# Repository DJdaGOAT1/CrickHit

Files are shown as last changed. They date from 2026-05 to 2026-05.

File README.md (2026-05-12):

# CrickHit
### An Embedded Real-Time Cricket Game on the TI MSPM0G3507

---

## Project Overview

CrickHit is a real-time cricket batting game built from scratch on the **TI MSPM0G3507 LaunchPad** with a **ST7735R 128x160 TFT LCD**. The player controls a batsman using a slide potentiometer and physical switches to hit balls bowled with realistic curve trajectories. The game runs entirely on bare-metal interrupts with no RTOS, using fixed-point physics, sprite compositing, a custom 5-bit binary-weighted DAC for audio, and multilingual UI support.

Developed as the final project for **ECE 319H: Introduction to Embedded Systems (Honors)** at **The University of Texas at Austin**, Spring 2026.

**Authors:** Devansh Joshi and Calum Cheah

---

## Gameplay / Demo

A top-down cricket scene is rendered on the LCD. A bowler at the top of the screen delivers balls toward the stumps at the bottom. The player moves the batsman horizontally with a slide potentiometer and triggers left or right bat swings using physical switches.

A demo of CrickHit is available [here](https://youtu.be/25Vt4UJRmN4):

Video Thumbnail Title (https://www.youtube.com/watch?v=25Vt4UJRmN4)

### Scoring

Runs are awarded based on how precisely the bat contacts the ball:

| Result | Condition | Runs |
|---|---|---|
| Perfect Hit | Ball within 3px of ideal contact point | +6 |
| Good Hit | Ball within 8px of ideal contact point | +4 |
| Hit | Ball within 14px of ideal contact point | +2 |
| Wide | Ball delivered too far from the batsman | +1 |
| Wicket (OUT) | Ball hits the stumps without being hit | Score resets |

Swinging on the correct side (left swing for balls approaching from the left, right swing for the right) gives a threshold bonus. Swinging on the wrong side applies a 2px penalty to all scoring thresholds, making it harder to score high.

### Ball Physics

Each delivery uses kinematic equations with 6-bit fixed-point arithmetic for sub-pixel precision:
- Initial horizontal velocity is randomized
- A curve acceleration (`ax`) is computed so the ball arcs toward the stumps
- Target position uses a Gaussian random distribution (Central Limit Theorem approximation) so slower deliveries aim more accurately at the stumps while faster ones scatter wider
- Speed-proportional jitter is added to the scoring calculation to prevent quantization lockout at high speeds, where the large step size would otherwise restrict the ball to only a few Y positions in the hit zone

### Wide Detection

A ball is called wide if it passes the batsman's reach without being hit:
- **Off-wide:** Ball passes more than 15px past the batsman's right edge
- **Leg-wide:** Ball is left of the pitch with a gap greater than 3px from the batsman's left edge

If a wide ball subsequently hits the stumps or gets hit by the bat, the wide run is revoked.

### Game Controls

| Input | Action |
|---|---|
| Slide potentiometer | Move batsman left/right |
| LEFT switch (PA25) | Swing bat to the left |
| RIGHT switch (PA27) | Swing bat to the right |
| TOP switch (PA24) | Increase ball delivery speed |
| BOTTOM switch (PA26) | Decrease ball delivery speed |
| TOP + BOTTOM | Return to home screen |
| LEFT + RIGHT | Pause / unpause |
| S1 (LaunchPad) | Enable speaker |
| S2 (LaunchPad) | Disable speaker |

A 1500ms cooldown is enforced between swings to prevent spam.

---

## Hardware

### Platform
- **MCU:** TI MSPM0G3507 LaunchPad (ARM Cortex-M0+, 80 MHz)
- **Display:** ST7735R 128x160 TFT LCD over SPI

### Pin Assignments

| Peripheral | Pin(s) | Function |
|---|---|---|
| SPI1 SCLK | PB9 | LCD clock |
| SPI1 CS | PB6 | LCD chip select |
| SPI1 MOSI | PB8 | LCD data |
| LCD Reset | PB15 | ST7735 !RST |
| LCD D/C | PA13 | ST7735 RS (Data/Command) |
| Slide Pot | PB18 (ADC1 Ch5) | Batsman horizontal position |
| 5-bit DAC | PB0-PB4 | Binary-weighted audio output |
| Speaker Enable | PB12 | Active-low speaker control |
| TOP Switch | PA24 | Increase ball speed |
| LEFT Switch | PA25 | Left bat swing |
| BOTTOM Switch | PA26 | Decrease ball speed |
| RIGHT Switch | PA27 | Right bat swing |
| LED 0 | PA15 | 2-run hit indicator |
| LED 1 | PA16 | 4-run hit indicator |
| LED 2 | PA17 | 6-run hit indicator |

### Required Components
- MSPM0G3507 LaunchPad
- ST7735R 128x160 TFT LCD
- Slide potentiometer
- 4 momentary push switches
- 5-bit binary-weighted DAC
- Speaker with enable circuit
- 3 LEDs with current-limiting resistors

### Custom PCB

We designed a custom PCB in KiCad that consolidates all of the hardware circuitry onto a single board. The PCB integrates the ST7735R LCD connector, the 5-bit binary-weighted DAC, the speaker amplifier circuit (MCP34119P), all four game switches, the slide potentiometer input, LED indicators, IR receiver (TSOP31438), a ULN2003B Darlington driver, UART debugging header, and TExaS connector -- all routed to the MSPM0G3507 LaunchPad. This eliminates the need for breadboard wiring and makes the entire system compact and reliable.

### 3D-Printed Enclosure

A custom controller-style enclosure was designed in **Autodesk Fusion** to house the PCB and LaunchPad together as a handheld game controller.




An STL of the enclosure is included in the `3D_Enclosure/`

---

## Software Architecture

### Interrupt-Driven Design

The entire game runs on three interrupt sources with no polling loops in the main thread:

| ISR | Source | Rate | Purpose |
|---|---|---|---|
| `TIMG12_IRQHandler` | TimerG12 | 30 Hz | Main game tick: polls ADC, updates all sprite positions, runs collision detection, sets render flag |
| `TIMG0_IRQHandler` | TimerG0 | 1 kHz | Swing cooldown timer (counts up to 1500ms between allowed swings) |
| SysTick | SysTick | 11 kHz | Streams audio samples through the 5-bit DAC |

The main loop blocks on a flag set by the 30 Hz ISR, then handles rendering, UI updates, and screen transitions. All ST7735 drawing occurs in main context only, never inside an ISR.

### Object-Oriented Sprite System

A `Sprite` base class provides position tracking, dirty-flag rendering, overlap detection, and background-aware erasure. Four derived classes implement the game objects:

**Ball** -- Fixed-point position (`fx`, `fy`) and velocity (`vx`, `vy`) with curve acceleration (`ax`). A 5-state machine drives the lifecycle:
```
IDLE --> BOWLING --> HIT_LEFT/HIT_RIGHT --> RESET --> IDLE
                 \-> (stump collision) --> RESET --> IDLE
```

**Batsman** -- Position mapped from the slide potentiometer ADC reading (calibrated range 1587-192). Left swing has 8 animation frames, right swing has 10. The current frame pointer is updated each game tick during a swing.

**Bowler** -- Cycles through 7 animation frames. Frame 4 is the release frame, which triggers ball delivery with randomized trajectory parameters.

**Stump** -- Two frames (intact and broken). On wicket, the broken frame displays for 30 game ticks (~1 second) before the OUT screen appears.

### Rendering Pipeline

The `Renderer` module composites sprites against the pitch background to prevent texture artifacts:

1. For each pixel in a sprite, check if it's transparent (`BG_COLOR = 0x9772`)
2. If transparent, fetch the corresponding pixel from the pitch bitmap (or outfield green if outside the pitch bounds)
3. White crease pixels in the pitch are substituted with pitch surface color to avoid visual bleed
4. The composed buffer is written as a single SPI transaction for flicker-free output

`EraseToBackground()` restores the pitch texture when a sprite moves, handling the partial-width erase case when the batsman slides left or right.

### Audio System

Three sound effects are stored as raw sample arrays and played through a 5-bit binary-weighted DAC at 11 kHz via SysTick:

| Sound | Samples | Trigger |
|---|---|---|
| IPL Stadium | 28,179 | Title screen crowd atmosphere |
| Bat Hit | 2,239 | Ball contacts bat |
| Stump Hit | 3,592 | Ball hits stumps (wicket) |

The speaker can be muted/unmuted at runtime via the LaunchPad S1/S2 buttons, controlled through GPIO PB12.

### Internationalization

The game supports **English** and **Spanish**, selectable on the home screen:
- TOP switch selects English, BOTTOM switch selects Spanish
- All UI strings ("Score"/"Puntaje", "Wide"/"Ancha", instruction text) are stored in a `Phrases[][]` lookup table
- A Devanagari (Hindi) font renderer (`HindiFont.h/cpp`) with 31 glyphs and diacritic support is included for future localization

---

## Project Structure

```
CrickHit/
|-- README.md
|-- LICENSE
|-- mspm0g3507.cmd                 Linker script
|
|-- src/                           Game source code
|   |-- Lab9HMain.cpp              Main game loop, ISRs, collision detection, game state
|   |-- GameDefs.h                 All constants: sprite dimensions, physics params, thresholds
|   |-- Sprites.h                  Sprite class hierarchy (Sprite, Ball, Batsman, Bowler, Stump)
|   |-- Sprite.cpp                 Base class: draw, erase, overlap detection
|   |-- Ball.cpp                   Fixed-point kinematics, trajectory, state machine
|   |-- Batsman.cpp                Potentiometer input mapping, swing animation
|   |-- Bowler.cpp                 Bowling animation, release frame detection
|   |-- Stump.cpp                  Intact/broken state, hit animation
|   |-- Renderer.h / .cpp          Background-compositing sprite renderer
|   |-- Screens.h / .cpp           Home, instruction, pause, and OUT screens + i18n
|   |-- Sound.h / .cpp             DAC audio playback (SysTick-driven)
|   |-- LED.h / .cpp               Hit-quality LED indicators
|   |-- Switch.h / .cpp            4-switch input reading
|   |-- SmallFont.h / .cpp         Numeric score display font
|   +-- HindiFont.h / .cpp         Devanagari script renderer (31 glyphs, 12x16px)
|
|-- inc/                           Hardware abstraction libraries (see Acknowledgments)
|   |-- Clock.h / .cpp             System clock configuration (80 MHz PLL)
|   |-- DAC5.h / .cpp              5-bit DAC GPIO driver
|   |-- LaunchPad.h / .cpp         LaunchPad GPIO and button initialization
|   |-- SPI.h / .cpp               SPI communication driver
|   |-- ST7735.h / .cpp            ST7735 LCD driver (drawing, text, bitmaps)
|   |-- SlidePot.h / .cpp          Slide potentiometer ADC driver
|   |-- TExaS.h / .cpp             TExaS grading and logic analyzer system
|   |-- Timer.h / .cpp             Hardware timer configuration and arming
|   |-- SysTick.s                  SysTick assembly routines
|   +-- msp.s                      MSP device assembly support
|
|-- images/                        Sprite assets
|   |-- images.h                   All sprite bitmap data as C arrays (RGB565, 16-bit)
|   |-- ball/                      Ball sprite source BMP
|   |-- batsman/                   Batsman idle + 7 swing frame BMPs
|   |-- bowler/                    7 bowling animation frame BMPs
|   |-- stump/                     Intact and broken stump BMPs
|   |-- pitch/                     35x140 pitch surface bitmap
|   +-- BmpConvert16.exe           BMP-to-RGB565 C array converter
|
|-- sounds/                        Audio assets
|   |-- sounds.h                   Audio sample arrays
|   |-- ipl_stadium.wav            Title screen crowd audio
|   |-- bat_hit.wav                Bat contact sound effect
|   +-- stump.wav                  Wicket sound effect
|
|-- PCB_Design/                    KiCad project for the custom game PCB
|   |-- CrickHit_PCB.kicad_sch    Schematic
|   |-- CrickHit_PCB.kicad_pcb    PCB layout
|   |-- CrickHit_PCB.kicad_pro    Project file
|   |-- utece.kicad_sym            Custom symbol library
|   +-- logo.bmp                   Board silkscreen logo
|
|-- 3D_Enclosure/                  STL file for the controller enclosure
|   +-- Enclosure.stl
|
|-- tools/                         Development utilities
|   |-- curve.py                   Ball trajectory simulation for tuning physics
|   +-- flood_fill_sprites.py      Sprite transparency preprocessing
|
|-- ticlang/
|   +-- startup_mspm0g3507_ticlang.c   MCU startup and vector table
|
+-- targetConfigs/
    +-- MSPM0G3507.ccxml           Debug target configuration
```

---

## Building and Flashing

### Prerequisites
- **Code Composer Studio (CCS)** with the TI CLANG compiler (v4.0+)
- **MSPM0 SDK** (v2.9+)
- MSPM0G3507 LaunchPad with hardware wired per the pin assignments above

### Setup
1. Clone this repository into your CCS workspace
2. **File > Import > CCS Projects**, point to the cloned folder
3. Ensure the MSPM0 SDK is installed and `COM_TI_MSPM0_SDK_INSTALL_DIR` is set
4. Build the project -- the `inc/` folder contains all necessary driver libraries, so no external ValvanoWare dependency is needed
5. Connect the LaunchPad via USB and flash

The `inc/` directory contains the hardware abstraction libraries that originally lived in a shared `MSPM0_ValvanoWare/inc/` directory. Include paths have been updated so this project builds standalone.

---

## Development Utilities

**`curve.py`** -- Python script that simulates ball trajectories with the same kinematic equations used in the game. Plots predicted paths for tuning physics constants (velocity, acceleration, target variance) without reflashing the board.

**`flood_fill_sprites.py`** -- Post-processes `images.h` after BMP-to-C conversion. Flood-fills exterior background pixels with the transparent color (`0x9772`) while preserving interior white pixels (bat highlights, ball shine, etc.) that should not be treated as transparent during compositing.

---

## Acknowledgments

This project was built for **ECE 319H: Introduction to Embedded Systems (Honors)** at **The University of Texas at Austin**, taught by **Professor Ramesh Yerraballi**. Thank you to Dr. Yerraballi, Dr. Valvano, Dr. Chin, Dr. Holt, and the ECE319 TAs for their instruction and support throughout ECE319H!

The hardware abstraction libraries in the `inc/` directory -- Clock, DAC5, LaunchPad, SPI, ST7735, SlidePot, TExaS, and Timer -- were written by **Jonathan Valvano** as part of the [MSPM0 ValvanoWare](http://users.ece.utexas.edu/~valvano/) curriculum framework. These drivers provide the foundational embedded systems infrastructure (clock configuration, SPI communication, LCD rendering, ADC interfacing, timer management) that CrickHit is built on.

---

## Authors

**Devansh Joshi** -- [GitHub](https://github.com/devanshjoshi08)  
**Calum Cheah** -- [GitHub](https://github.com/CalumCheah)

---

## License

This project is licensed under the [MIT License](LICENSE).

The hardware abstraction libraries in `inc/` are provided by Jonathan Valvano and Texas Instruments under their own respective terms and are not covered by the MIT License.

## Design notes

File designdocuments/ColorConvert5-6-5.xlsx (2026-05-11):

red | green | blue | 565
0 | 255 | 120 | 0x7FE0 | 0x7FE0, // 0, 255, 120

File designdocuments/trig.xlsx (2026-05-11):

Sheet: 64
 | 2 |  | 64
angle | vx | vy | ix | iy
0 | 2 | 0 | 128 | 0
0.09817477042 | 1.990369453 | 0.1960342807 | 127 | 13
0.1963495408 | 1.961570561 | 0.390180644 | 126 | 25
0.2945243113 | 1.913880671 | 0.5805693545 | 122 | 37
0.3926990817 | 1.847759065 | 0.7653668647 | 118 | 49
0.4908738521 | 1.763842529 | 0.9427934737 | 113 | 60
0.5890486225 | 1.662939225 | 1.111140466 | 106 | 71
0.687223393 | 1.546020907 | 1.268786568 | 99 | 81
0.7853981634 | 1.414213562 | 1.414213562 | 91 | 91
0.8835729338 | 1.268786568 | 1.546020907 | 81 | 99
0.9817477042 | 1.111140466 | 1.662939225 | 71 | 106
1.079922475 | 0.9427934737 | 1.763842529 | 60 | 113
1.178097245 | 0.7653668647 | 1.847759065 | 49 | 118
1.276272016 | 0.5805693545 | 1.913880671 | 37 | 122
1.374446786 | 0.390180644 | 1.961570561 | 25 | 126
1.472621556 | 0.1960342807 | 1.990369453 | 13 | 127
1.570796327 | -7.656635742e-16 | 2 | 0 | 128
1.668971097 | -0.1960342807 | 1.990369453 | -13 | 127
1.767145868 | -0.390180644 | 1.961570561 | -25 | 126
1.865320638 | -0.5805693545 | 1.913880671 | -37 | 122
1.963495408 | -0.7653668647 | 1.847759065 | -49 | 118
2.061670179 | -0.9427934737 | 1.763842529 | -60 | 113
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

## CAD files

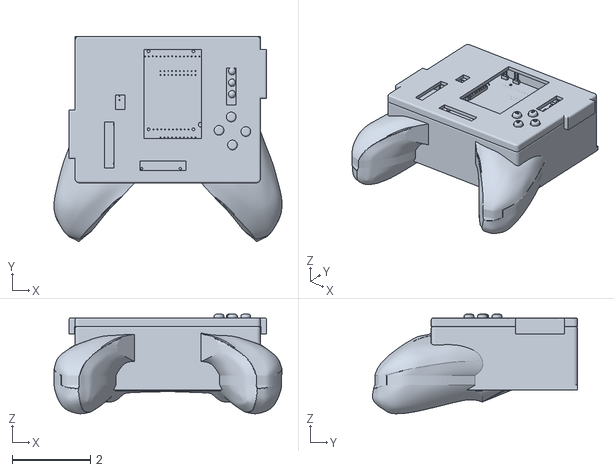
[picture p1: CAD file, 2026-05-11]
3D_Enclosure/Enclosure.stl
5.84 x 5.26 x 2.55

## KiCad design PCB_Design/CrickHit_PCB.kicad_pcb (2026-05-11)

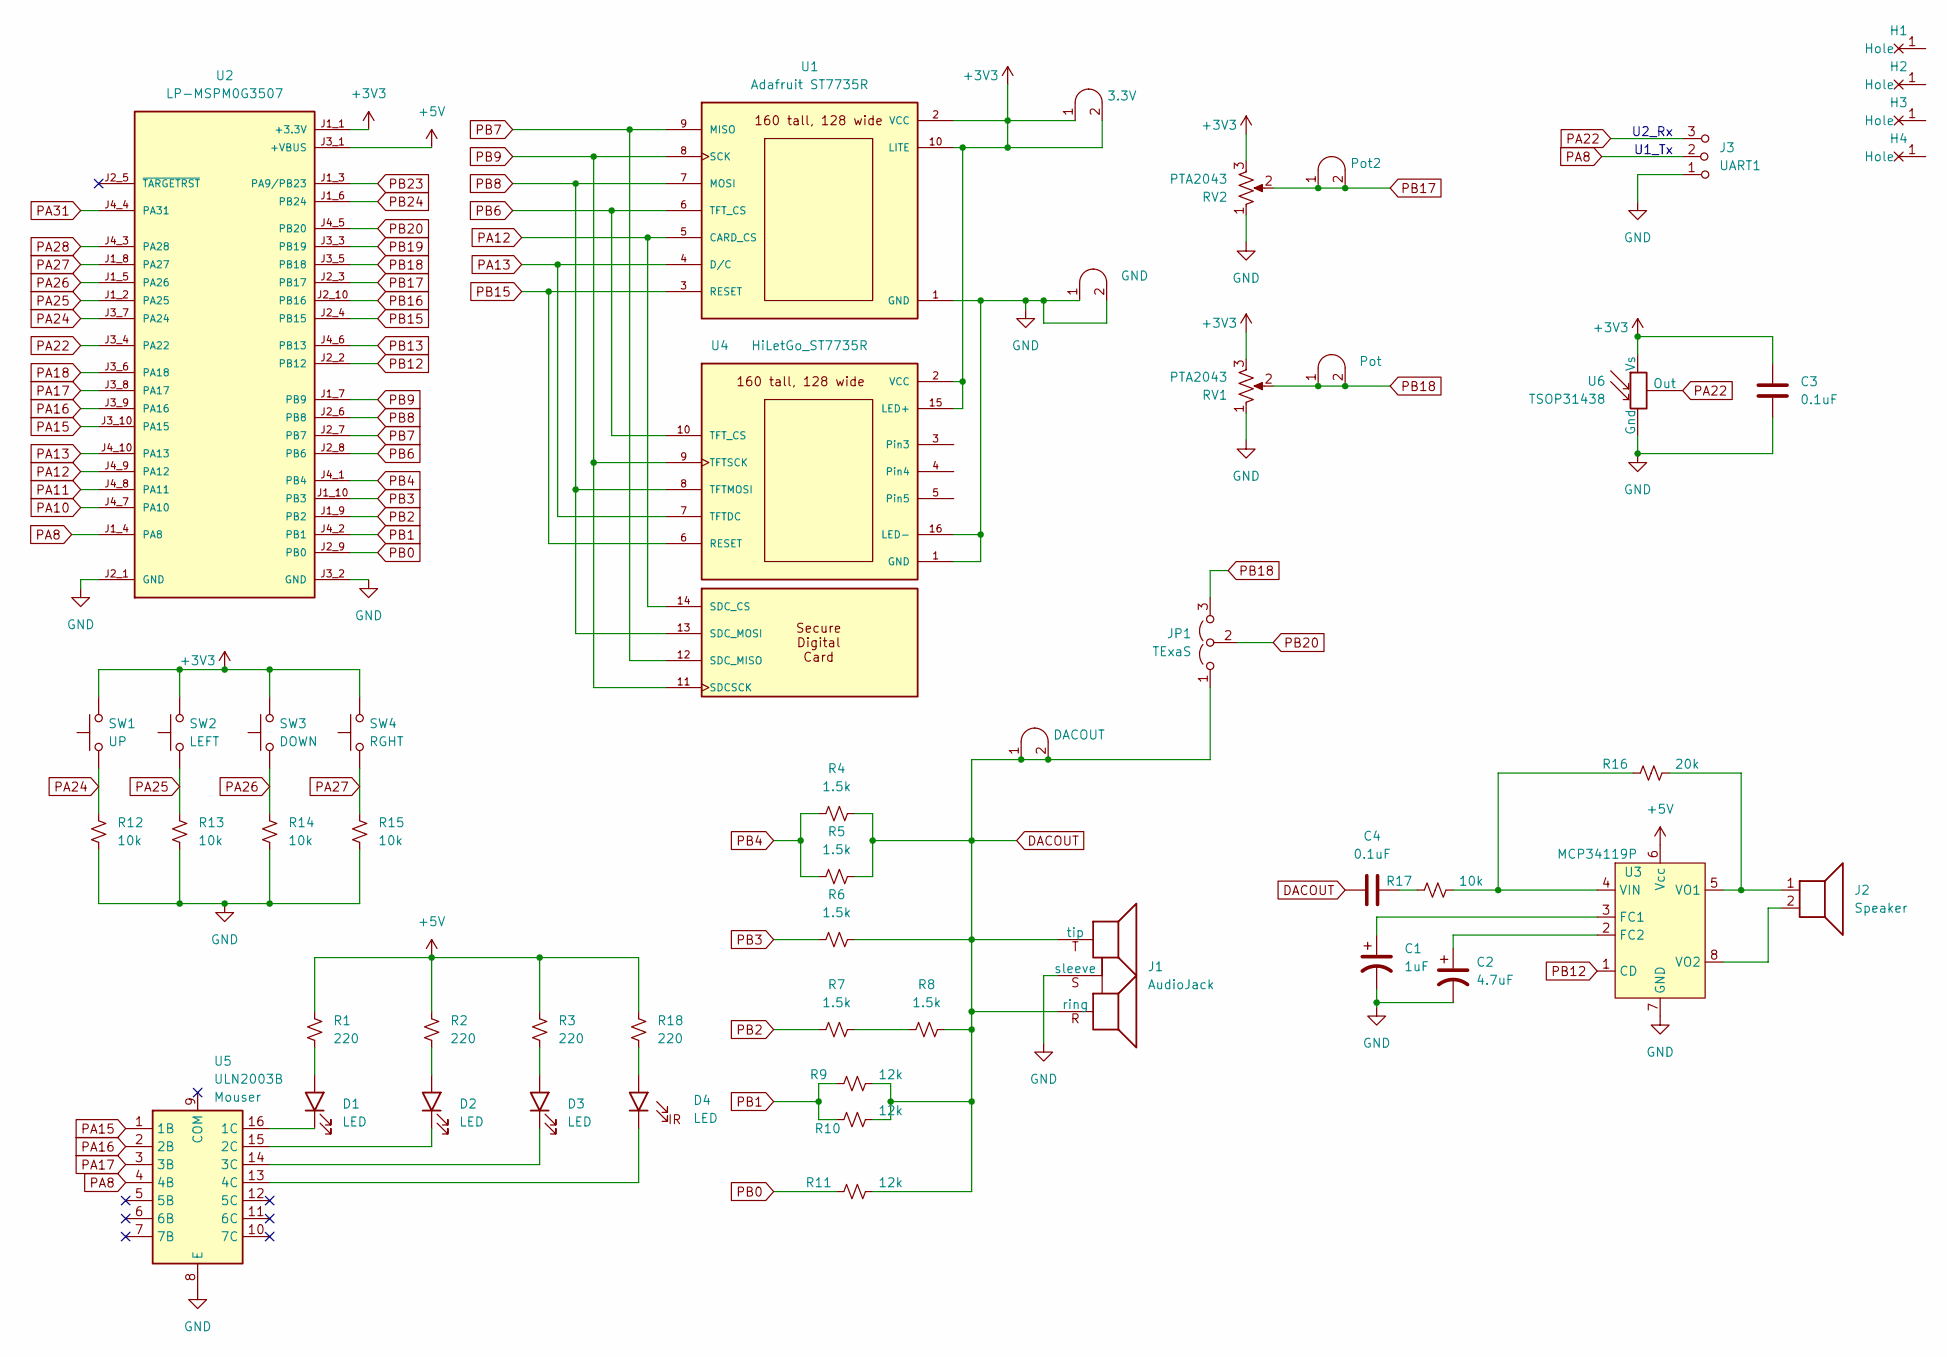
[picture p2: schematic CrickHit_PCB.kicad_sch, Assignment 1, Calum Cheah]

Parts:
C1: 1uF; CP_Radial_Tantal200mil
C2: 4.7uF; CP_Radial_Tantal200mil
C3, C4: 0.1uF; C_Axial_200mil
D1, D2, D3, D4: LED; LED_D5.0mm
H1, H2, H3, H4: MountingHole_4_40
J1: AudioJack; Jack_3.5mm_CUI_SJ1-3523N_Horizontal
J2: Speaker; PinHeader_1x02_P2.54mm_Vertical
J3: UART1; PinHeader_1x03_P2.54mm_Vertical
J4: Pot; Testpoint_1x02_P2.54mm
J5: Pot2; Testpoint_1x02_P2.54mm
J6: GND; Testpoint_1x02_P2.54mm
J7: DACOUT; Testpoint_1x02_P2.54mm
JP1: TExaS; PinHeader_1x03_P2.54mm_Vertical
R1, R2, R3, R18: 220; R_Axial_DIN0204_L3.6mm_D1.6mm_P7.62mm_Horizontal
R4, R5, R6, R7, R8: 1.5k; R_Axial_DIN0204_L3.6mm_D1.6mm_P7.62mm_Horizontal
R9, R10, R11: 12k; R_Axial_DIN0204_L3.6mm_D1.6mm_P7.62mm_Horizontal
R12, R13, R14, R15, R17: 10k; R_Axial_DIN0204_L3.6mm_D1.6mm_P7.62mm_Horizontal
R16: 20k; R_Axial_DIN0204_L3.6mm_D1.6mm_P7.62mm_Horizontal
RV1, RV2: PTA2043; PTA2043pot
SW1: UP; SW_PUSH_6mm
SW2: LEFT; SW_PUSH_6mm
SW3: DOWN; SW_PUSH_6mm
SW4: RGHT; SW_PUSH_6mm
TP1: 3.3V; Testpoint_1x02_P2.54mm
U1: Adafruit ST7735R; adafruit_st7735r
U2: LP-MSPM0G3507; ti_LP_MSPM0G3507
U3: MCP34119P; DIP-8_W7.62mm_LongPads
U4: HiLetGo_ST7735R; hiletgo_st7735r
U5: ULN2003B; DIP-16_W7.62mm
U6: TSOP31438

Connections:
+3V3: C3.2, RV1.3, RV2.3, SW1.2, SW2.2, SW3.2, SW4.2, TP1.1 (A), TP1.2 (B), U1.2 (VCC), U1.10 (LITE), U2.J1_1 (+3.3V), U4.2 (VCC), U4.15 (LED+), U6.2 (Vs)
+5V: R1.1, R2.1, R3.1, R18.1, U2.J3_1 (+VBUS), U3.6 (Vcc)
DACOUT: C4.2, J1.R (ring), J1.T (tip), J7.1 (A), J7.2 (B), JP1.1 (A), R4.1, R5.1, R6.1, R8.1, R9.1, R10.1, R11.1
GND: C1.2, C2.2, C3.1, J1.S (sleeve), J3.1 (A), J6.1 (A), J6.2 (B), R12.2, R13.2, R14.2, R15.2, RV1.1, RV2.1, U1.1 (GND), U2.J2_1 (GND), U2.J3_2 (GND), U3.7 (GND), U4.1 (GND), U4.16 (LED-), U5.8 (E), U6.1 (Gnd)
unnamed: C4.1, R17.2
unnamed: D1.2 (A), R1.2
unnamed: D1.1 (K), U5.16 (1C)
unnamed: D2.2 (A), R2.2
unnamed: D2.1 (K), U5.15 (2C)
unnamed: D3.2 (A), R3.2
unnamed: D3.1 (K), U5.14 (3C)
unnamed: D4.2 (A), R18.2
unnamed: D4.1 (K), U5.13 (4C)
unnamed: R7.1, R8.2
unnamed: C1.1, U3.3 (FC1)
unnamed: C2.1, U3.2 (FC2)
unnamed: R16.2, R17.1, U3.4 (VIN)
unnamed: J2.1, R16.1, U3.5 (VO1)
unnamed: J2.2, U3.8 (VO2)
PA8: J3.2 (B), U2.J1_4 (PA8), U5.4 (4B)
PA10: U2.J4_7 (PA10)
PA11: U2.J4_8 (PA11)
PA12: U1.5 (CARD_CS), U2.J4_9 (PA12), U4.14 (SDC_CS)
PA13: U1.4 (D/C), U2.J4_10 (PA13), U4.7 (TFTDC)
PA15: U2.J3_10 (PA15), U5.1 (1B)
PA16: U2.J3_9 (PA16), U5.2 (2B)
PA17: U2.J3_8 (PA17), U5.3 (3B)
PA18: U2.J3_6 (PA18)
PA22: J3.3 (C), U2.J3_4 (PA22), U6.3 (Out)
PA24: R12.1, SW1.1, U2.J3_7 (PA24)
PA25: R13.1, SW2.1, U2.J1_2 (PA25)
PA26: R14.1, SW3.1, U2.J1_5 (PA26)
PA27: R15.1, SW4.1, U2.J1_8 (PA27)
PA28: U2.J4_3 (PA28)
PA31: U2.J4_4 (PA31)
PB0: R11.2, U2.J2_9 (PB0)
PB1: R9.2, R10.2, U2.J4_2 (PB1)
PB2: R7.2, U2.J1_9 (PB2)
PB3: R6.2, U2.J1_10 (PB3)
PB4: R4.2, R5.2, U2.J4_1 (PB4)
PB6: U1.6 (TFT_CS), U2.J2_8 (PB6), U4.10 (TFT_CS)
PB7: U1.9 (MISO), U2.J2_7 (PB7), U4.12 (SDC_MISO)
PB8: U1.7 (MOSI), U2.J2_6 (PB8), U4.8 (TFTMOSI), U4.13 (SDC_MOSI)
PB9: U1.8 (SCK), U2.J1_7 (PB9), U4.9 (TFTSCK), U4.11 (SDCSCK)
PB12: U2.J2_2 (PB12), U3.1 (CD)
PB13: U2.J4_6 (PB13)
PB15: U1.3 (RESET), U2.J2_4 (PB15), U4.6 (RESET)
PB16: U2.J2_10 (PB16)
PB17: J5.1 (A), J5.2 (B), RV2.2, U2.J2_3 (PB17)
PB18: J4.1 (A), J4.2 (B), JP1.3 (B), RV1.2, U2.J3_5 (PB18)
PB19: U2.J3_3 (PB19)
PB20: JP1.2 (C), U2.J4_5 (PB20)
PB23: U2.J1_3 (PA9/PB23)
PB24: U2.J1_6 (PB24)

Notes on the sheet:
U2_Rx
U1_Tx

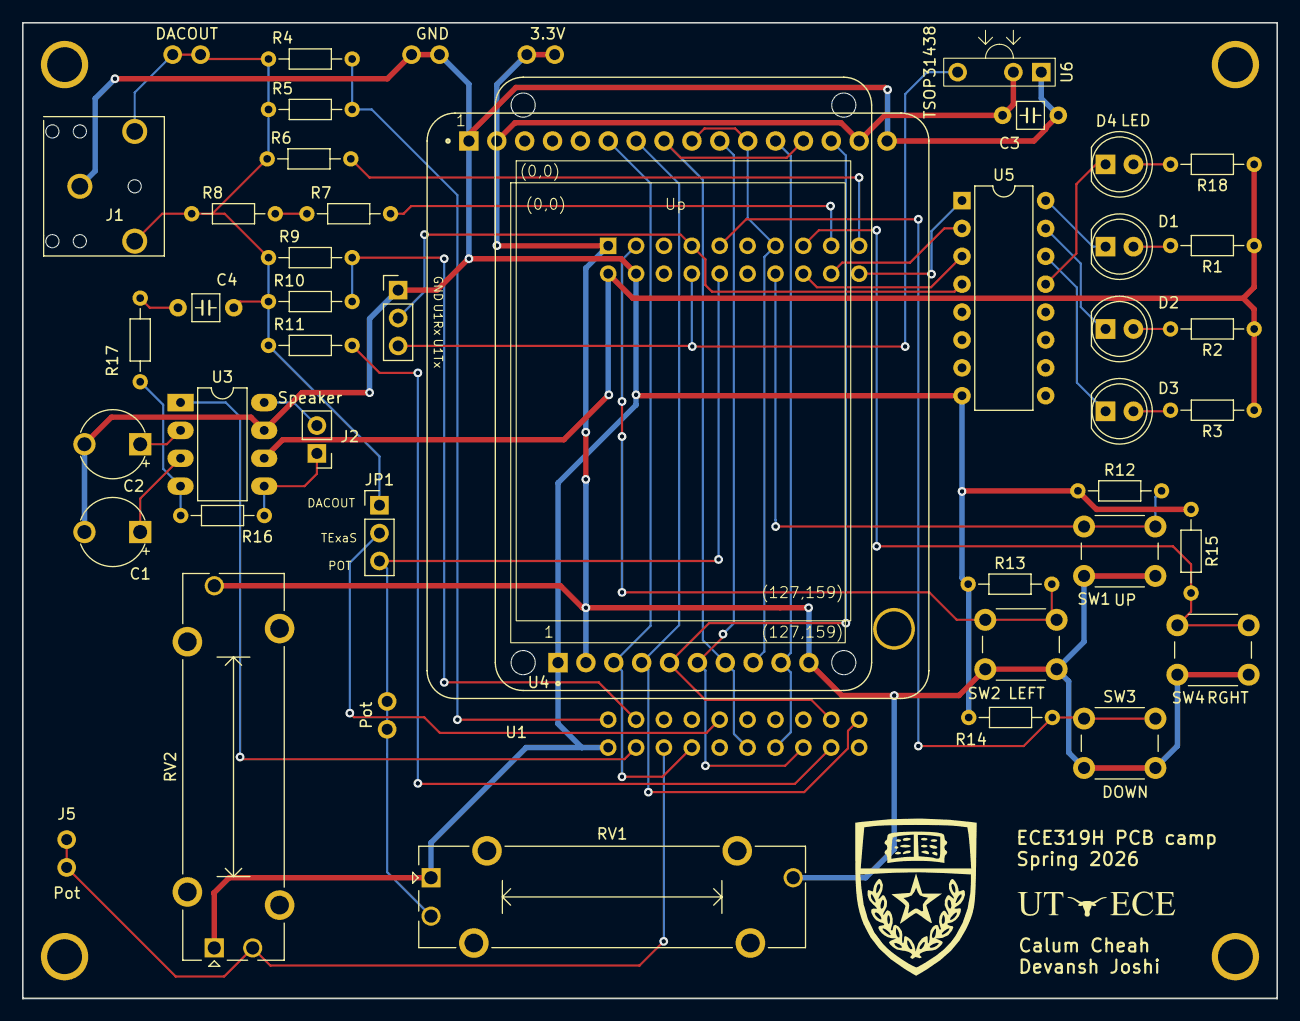
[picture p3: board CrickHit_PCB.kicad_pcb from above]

Board: 2 copper layers, 114.3 x 88.9 mm, 51 parts (1 on the bottom side), 44 nets.

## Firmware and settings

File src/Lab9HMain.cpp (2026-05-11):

// Lab9HMain.cpp
// Runs on MSPM0G3507
// Lab 9 ECE319H
// Devansh Joshi and Calum Cheah
// Last Modified: January 12, 2026
//
// File layout:
//   GameDefs.h   – all #defines, Ball/Batsman struct definitions
//   Renderer.h/cpp – ComposeAndDraw, EraseToBackground
//   Screens.h/cpp  – HomeScreen, InstructionScreen, language data
//   Lab9HMain.cpp  – globals, ISR handlers, game logic, main()

#include <stdio.h>
#include <stdint.h>
#include <ti/devices/msp/msp.h>
#include "../inc/ST7735.h"
#include "../inc/Clock.h"
#include "../inc/LaunchPad.h"
#include "../inc/TExaS.h"
#include "../inc/Timer.h"
#include "../inc/SlidePot.h"
#include "../inc/DAC5.h"
#include "SmallFont.h"
#include "LED.h"
#include "Switch.h"
#include "Sound.h"
#include "../images/images.h"
#include "GameDefs.h"
#include "Renderer.h"
#include "Screens.h"
#include "Sprites.h"
extern "C" void __disable_irq(void);
extern "C" void __enable_irq(void);
extern "C" void TIMG0_IRQHandler(void);
extern "C" void TIMG12_IRQHandler(void);

void PLL_Init(void){
  // Clock_Init40MHz();
  Clock_Init80MHz(0);
}

SlidePot Sensor(1587, 192);

// Random number generator 
uint32_t M = 1;
uint32_t Random32(void){
  M = 1664525*M + 1013904223;
  return M;
}
uint32_t Random(uint32_t n){
  return (Random32() >> 16) % n;
}

// Use central limit theorem to approximate a gaussian distribution by averaging 2 random samples
int16_t GaussianRandom(int16_t center, int16_t range) {
  int32_t sum = (int32_t) Random(range) + Random(range);
  sum -= (int32_t)(range); // Shift center back to zero after summing the samples

  return center + (int16_t)(sum >> 1); // divide sum by 2 to average, add variance to center
}

// Pointers to image arrays for animations
const uint16_t* bowler_frames[] = {bowler1, bowler2, bowler3, bowler4, bowler5, bowler6, bowler7};
const uint16_t* stump_frames[] = {stump1, stump2};
const uint16_t* left_swing_frames[] = {batsman_idle, left_batsman1, left_batsman1, left_batsman2,
  left_batsman3, left_batsman3, left_batsman3, right_batsman1};
const uint16_t* right_swing_frames[] = {batsman_idle, right_batsman1, right_batsman1, right_batsman1,
    right_batsman2, right_batsman3, right_batsman4, right_batsman4,
    right_batsman4, right_batsman1};

// Global class instances
Ball cricket_ball;
Bowler bowler(bowler_frames);
Stump stump(stump_frames);
Batsman batsman(batsman_idle, left_swing_frames, right_swing_frames, 8, 10);

// Game state globals
volatile bool flag        = false;
volatile bool game_paused = false;
uint8_t stump_timer = 0;
bool has_swung = false;
uint32_t swing_time = 0;

// flags for game/sound events
bool event_wicket = false;
bool event_hit    = false;
bool event_wide   = false;
bool wide_called  = false;
bool wide_scored  = false;

uint32_t score             = 0;
uint32_t score_prev_digits = 1;

//TExaS logic analyser probe 
uint8_t TExaS_LaunchPadLogicPB27PB26(void){
  return (0x80 | ((GPIOB->DOUT31_0 >> 26) & 0x03));
}

void checkCollisions() {
  if (cricket_ball.state != BALL_BOWLING) {
    return;
  }

  bool in_bat_x = (cricket_ball.x >= batsman.x && cricket_ball.x <= batsman.x + BATSMAN_W);
  bool in_bat_y = (cricket_ball.y >= BAT_HIT_Y1 && cricket_ball.y <= BAT_HIT_Y2);

  // Wide detection (fires once per delivery, only when ball reaches batsman)
  if(cricket_ball.y >= BATSMAN_Y && !wide_called){
    wide_called = true;
    bool leg_wide = (cricket_ball.x < PITCH_X) && ((batsman.x - cricket_ball.x) > LEG_WIDE_MARGIN);
    bool off_wide = (cricket_ball.x - (batsman.x + BATSMAN_W)) >= WIDE_THRESHOLD;
    if(leg_wide || off_wide){
      event_wide  = true;
      wide_scored = true;
      score += 1;
    }
  }

  // Bat contact
  if(in_bat_x && in_bat_y && batsman.isSwinging()){
    if(wide_scored){ score -= 1; wide_scored = false; event_wide = false; }
    event_hit = true;
    int8_t err = ((BAT_HIT_Y1 + BAT_HIT_Y2) / 2) - cricket_ball.y;
    if(err < 0) err = -err;
    cricket_ball.hit(batsman.isSwingingLeft(), err);

    // Add speed-proportional jitter to break quantisation at high speeds.
    // At fast ball speeds the large step size means only a few Y positions
    // are reachable in the hit zone, locking scores to one value.
    // Jitter range scales with speed so all scores (0-6) stay possible.
    int16_t speed_px = cricket_ball.speed >> BALL_FIXED_POINT;
    int8_t jitter = (int8_t)(Random(speed_px + 1)) - (speed_px >> 1);
    int8_t adj_err = err + jitter;
    if(adj_err < 0) adj_err = -adj_err;

    // Check if ball position relative to batsman matches the swing side
    int16_t x_err = (cricket_ball.x + (BALL_W >> 1)) - (batsman.x + (BATSMAN_W >> 1));

    // Add penalty if ball is not on same side as swing direction (centered ball is not penalized)
    int8_t threshold_modifier = 0;
    if (x_err != 0 && (x_err < 0) != batsman.isSwingingLeft()) {
      threshold_modifier -= SWING_SIDE_PENALTY;
    }

    if(adj_err <=  SIX_THRESHOLD + threshold_modifier){ score += 6; LED_On(0x04); }
    else if(adj_err <=  FOUR_THRESHOLD + threshold_modifier){ score += 4; LED_On(0x02); }
    else if(adj_err <= TWO_THRESHOLD + threshold_modifier){ score += 2; LED_On(0x01); }
  }

  // Stump collision
  bool in_stump_x = (cricket_ball.x >= STUMP_HIT_X1 && cricket_ball.x <= STUMP_HIT_X2);
  if(in_stump_x && cricket_ball.y >= STUMP_HIT_Y) {
    if(wide_scored){ score -= 1; wide_scored = false; event_wide = false; }
    event_wicket = true;
    stump.hit();
    stump_timer = STUMP_BROKEN_FRAMES;
    cricket_ball.reset();
    cricket_ball.reset_timer = STUMP_BROKEN_FRAMES;
  }
}

// Swing-cooldown ISR (1 kHz, TimerG0) 
void TIMG0_IRQHandler(void){
  if((TIMG0->CPU_INT.IIDX) == 1){
    swing_time++;
    if(swing_time > SWING_COOLDOWN){
      has_swung  = false;
      swing_time = SWING_COOLDOWN;
    }
  }
}

// 30 Hz game-tick ISR (TimerG12) 
void TIMG12_IRQHandler(void){
  if((TIMG12->CPU_INT.IIDX) == 1){
    GPIOB->DOUTTGL31_0 = GREEN;
    GPIOB->DOUTTGL31_0 = GREEN;

    if(!game_paused){
      // Batsman x position from PB18 slide pot
      batsman.updatePos(Sensor.In());

      // Update all objects
      batsman.update();
      cricket_ball.update();
      stump.update();

      // Bowler animation & ball release
      if(cricket_ball.state == BALL_IDLE){
        bowler.update();
        if(bowler.isReleaseFrame()){
          int16_t vx = (int16_t)((Random((BALL_MAX_VX<<1) + 1)) - BALL_MAX_VX); // Get random vx

          // Vary targetX to get occasional misses
          int16_t variance = BALL_TARGET_VAR - (cricket_ball.speed >> BALL_FIXED_POINT);
          if (variance < 20) variance = 20; // Put minimum on spread
          int16_t targetX = GaussianRandom(BALL_TARGET_X, variance) << BALL_FIXED_POINT;

          // Adjust ax to curve towards stump
          // ax = (2*((targetX-initialX) - vx*t)) / (t*t)
          // t = number of frames it will take for ball to hit stump
          int16_t frames = (int16_t) ((BALL_TARGET_Y - BALL_RELEASE_Y) / (cricket_ball.speed >> BALL_FIXED_POINT));
          int16_t ax = (2*((targetX - (BALL_RELEASE_X<<BALL_FIXED_POINT)) - (vx*frames))) / (frames*frames);

          cricket_ball.bowl(BALL_RELEASE_X, BALL_RELEASE_Y, vx, cricket_ball.speed, ax);
          wide_called = false;
          wide_scored = false;
        }
      }

      // Stump broken-frame timer
      if(stump.isBroken() && stump_timer > 0){
        if(--stump_timer == 0) stump.reset();
      }

      checkCollisions();

      GPIOB->DOUTTGL31_0 = GREEN;
    } // end if(!game_paused)

    flag = true;  // always signal main loop, even while paused
  }
}

// Test mains (rename main1/2/3/4 - main to use) 
int main1(void){
    char l;
  __disable_irq();
  PLL_Init();
  LaunchPad_Init();
  ST7735_InitPrintf(INITR_REDTAB);
  ST7735_FillScreen(0x0000);
  for(int myPhrase = 0; myPhrase <= 2; myPhrase++){
    for(int myL = 0; myL <= 3; myL++){
      ST7735_OutString((char *)Phrases[myLanguage][myL]);
      ST7735_OutChar(' ');
      ST7735_OutString((char *)Phrases[myPhrase][myL]);
      ST7735_OutChar(13);
    }
  }
  Clock_Delay1ms(3000);
  ST7735_FillScreen(0x0000);
  l = 128;
  while(1){
    Clock_Delay1ms(2000);
    for(int j = 0; j < 3; j++){
      for(int i = 0; i < 16; i++){
        ST7735_SetCursor(7*j+0, i); ST7735_OutUDec(l);
        ST7735_OutChar(' '); ST7735_OutChar(' ');
        ST7735_SetCursor(7*j+4, i); ST7735_OutChar(l);
        l++;
      }
    }
  }
}

int main2(void){
  __disable_irq(); PLL_Init(); LaunchPad_Init();
  ST7735_InitPrintf(INITR_REDTAB);
  ST7735_FillScreen(ST7735_BLACK);
  ST7735_DrawBitmap(22, 159, PlayerShip0, 18, 8);
  ST7735_DrawBitmap(53, 151, Bunker0, 18, 5);
  ST7735_DrawBitmap(42, 159, PlayerShip1, 18, 8);
  ST7735_DrawBitmap(62, 159, PlayerShip2, 18, 8);
  ST7735_DrawBitmap(82, 159, PlayerShip3, 18, 8);
  ST7735_DrawBitmap( 0,   9, SmallEnemy10pointA, 16, 10);
  ST7735_DrawBitmap(20,   9, SmallEnemy10pointB, 16, 10);
  ST7735_DrawBitmap(40,   9, SmallEnemy20pointA, 16, 10);
  ST7735_DrawBitmap(60,   9, SmallEnemy20pointB, 16, 10);
  ST7735_DrawBitmap(80,   9, SmallEnemy30pointA, 16, 10);
  for(uint32_t t = 500; t > 0; t -= 5){
    SmallFont_OutVertical(t, 104, 6);
    Clock_Delay1ms(50);
  }
  ST7735_FillScreen(0x0000);
  ST7735_SetCursor(1, 1); ST7735_OutString((char *)"GAME OVER");
  ST7735_SetCursor(1, 2); ST7735_OutString((char *)"Nice try,");
  ST7735_SetCursor(1, 3); ST7735_OutString((char *)"Earthling!");
  ST7735_SetCursor(2, 4); ST7735_OutUDec(1234);
  while(1){}
}

int main3(void){
  __disable_irq(); PLL_Init(); LaunchPad_Init();
  Switch_Init(); LED_Init();
  while(1){
    uint32_t in = Switch_In();
    if(in & 2) LED_On(0x1); else LED_Off(0x1);
    if(in & 8) LED_On(0x2); else LED_Off(0x2);
  }
}

int main4(void){ uint32_t last = 0, now;
  __disable_irq(); PLL_Init(); LaunchPad_Init();
  Switch_Init(); LED_Init(); Sound_Init();
  TExaS_Init(ADC0, 6, 0);
  __enable_irq();
  while(1){
    now = Switch_In();
    if((last==0)&&(now==1)) Sound_IPLStadium();
    if((last==0)&&(now==2)) Sound_StumpHit();
    if((last==0)&&(now==4)) Sound_BatHit();
    last = now;
  }
}

// ResetGameState 
static void ResetGameState(void){
  score = 0; score_prev_digits = 1;
  cricket_ball.reset();
  cricket_ball.state = BALL_IDLE;
  cricket_ball.speed = BALL_MIN_VY;
  cricket_ball.reset_timer = 0;
  bowler.reset();
  batsman.reset();
  stump.reset();
  stump_timer = 0;
  event_wicket = false; event_hit = false; event_wide = false;
  wide_called = false; wide_scored = false; has_swung = false;
  swing_time = 0; flag = false; game_paused = false;
}

// Main 
// ALL ST7735 OUTPUT MUST OCCUR IN MAIN (or functions called from main)
int main(void){
  __disable_irq();
  PLL_Init();
  LaunchPad_Init();
  ST7735_InitPrintf(INITR_REDTAB);

  Sensor.Init();
  Switch_Init();
  LED_Init();
  Sound_Init();
  TExaS_Init(0, 0, &TExaS_LaunchPadLogicPB27PB26);

  Speaker_Enable();

  TimerG0_IntArm(1000, 40, 0);              // 1 kHz swing cooldown
  TimerG12_IntArm(80000000 / 30, 2);        // 30 Hz game tick
  __enable_irq();

  // Seed RNG
  M = Sensor.In();
  M ^= SysTick->VAL;

  while(1){  // outer loop: home - game - repeat
    HomeScreen();         // plays IPL audio; blocks until language chosen
    InstructionScreen();  // shows controls; blocks until any switch pressed
    ResetGameState();

    ST7735_FillScreen(BG_COLOR);
    ST7735_DrawBitmap(PITCH_X, PITCH_Y + PITCH_H - 1, pitch, PITCH_W, PITCH_H);

    // Per-round locals (re-initialised every cycle)
    int16_t prev_batsman_x = batsman.x;
    const unsigned short* prev_batsman_img = nullptr;
    uint8_t prev_bowler_idx = 0xFF;
    uint8_t prev_stump_idx = 0xFF;
    uint8_t wide_display = 0;
    bool wide_shown = false;
    uint32_t prev_in = 0;
    bool back_to_home = false;
    uint8_t out_delay = 0;        // countdown before showing OUT popup

    while(!back_to_home){

      while(flag == 0);  // wait for 30 Hz tick (set even when paused)
      flag = false;

      // ISR events
      if(event_wicket){
        event_wicket = false;
        Sound_StumpHit();
        out_delay = STUMP_BROKEN_FRAMES;  // start countdown, let game keep rendering
        // Revoke wide display if the ball curved back into the stump
        if(!wide_scored){ wide_display = 0; }
      }
      if(event_hit){
        event_hit = false; Sound_BatHit();
        if(!wide_scored){ wide_display = 0; }
      }
      if(event_wide)  { event_wide = false; wide_display = 60; }

      // Score display
      uint8_t  lbl_len = (myLanguage == Spanish) ? 9 : 7;
      uint32_t score_digs = (score < 10) ? 1 : (score < 100) ? 2 : (score < 1000) ? 3 : 4;
      if(score_digs < score_prev_digits)
        ST7735_FillRect((lbl_len + score_digs) * 6, 0,(score_prev_digits - score_digs) * 6, 10, BG_COLOR);
      score_prev_digits = score_digs;
      ST7735_SetCursor(0, 0);
      if(myLanguage == Spanish) printf("Puntaje: %d", score);
      else printf("Score: %d",   score);

      // Wide / Ancha display
      if(wide_display > 0){
        wide_display--;
        if(!wide_shown){
          ST7735_SetCursor(0, 1);
          if(myLanguage == Spanish) printf("Ancha!"); else printf("Wide!");
          wide_shown = true;
        }
      } else if(wide_shown){
        ST7735_FillRect(0, 10, 36, 10, BG_COLOR);
        wide_shown = false;
      }

      uint32_t in = Switch_In();

      // TOP+BOT = home;  L+R = pause toggle
      bool tb = (in & 0x5) == 0x5;
      bool lr = (in & 0xA) == 0xA;
      bool lr_was = (prev_in & 0xA) == 0xA;

      if(tb){ back_to_home = true; break; }

      if(lr && !lr_was){
        game_paused = !game_paused;
        if(game_paused){
          DrawPausePopup();
        } else {
          ST7735_FillScreen(BG_COLOR);
          ST7735_DrawBitmap(PITCH_X, PITCH_Y + PITCH_H - 1, pitch, PITCH_W, PITCH_H);
          prev_bowler_idx = 0xFF;
          prev_stump_idx = 0xFF;
          prev_batsman_img = nullptr;
          wide_shown = false;
          bowler.dirty = true;
          stump.dirty = true;
          batsman.dirty = true;
          if(cricket_ball.state != BALL_IDLE) cricket_ball.dirty = true;
        }
      }
      uint32_t prev_in_snap = prev_in;
      prev_in = in;

      if(game_paused) continue;

      // Speed controls (TOP alone / BOT alone)
      if((in & 1) && !(prev_in_snap & 1) && cricket_ball.speed < BALL_MAX_VY) cricket_ball.speed+=(1<<BALL_FIXED_POINT);
      if((in & 4) && !(prev_in_snap & 4) && cricket_ball.speed > BALL_MIN_VY) cricket_ball.speed-=(1<<BALL_FIXED_POINT);

      // Swing (guard against L+R combo)
      if(!lr && !batsman.isSwinging() && !has_swung){
        if(in & 2){
          batsman.startSwing(true);
          has_swung = true;
          swing_time = 0;
        }
        else if(in & 8){
          batsman.startSwing(false);
          has_swung = true;
          swing_time = 0;
        }
      }

      // Speaker mute controls
      if(LaunchPad_InS1()==0x00040000 && LaunchPad_InS2()==0) Speaker_Enable();
      if(LaunchPad_InS2()==0x00200000 && LaunchPad_InS1()==0) Speaker_Disable();

      // Snapshot batsman state (avoid ISR race)
      int16_t snap_x = batsman.x;
      const unsigned short* snap_img = batsman.image;

      // Erase ball; mark overlapped sprites dirty
      // Use prevOverlaps because the erase happens at the ball's previous
      // position, not its current one — otherwise sprites that the erase
      // painted over won't be redrawn (background "trail" artifacts).
      if(cricket_ball.wasVisible()){
        cricket_ball.erasePrev();
        if (!bowler.dirty && cricket_ball.prevOverlaps(bowler)) {
          bowler.dirty = true;
        }
        if (!batsman.dirty && cricket_ball.prevOverlaps(batsman)) {
          batsman.dirty = true;
        }
        if (!stump.dirty && cricket_ball.prevOverlaps(stump)) {
          stump.dirty = true;
        }
      }

      if (bowler.dirty){
        bowler.draw();
      }
      if (stump.dirty){
        stump.draw();
      }
      if (batsman.dirty){
        if(snap_x != prev_batsman_x){
          int16_t top = BATSMAN_Y - BATSMAN_H + 1;
          if(snap_x > prev_batsman_x){
            int16_t sw = snap_x - prev_batsman_x; if(sw > BATSMAN_W) sw = BATSMAN_W;
            EraseToBackground(prev_batsman_x, top, sw, BATSMAN_H);
          } else {
            int16_t sw = prev_batsman_x - snap_x; if(sw > BATSMAN_W) sw = BATSMAN_W;
            EraseToBackground(prev_batsman_x + BATSMAN_W - sw, top, sw, BATSMAN_H);
          }
        }
        batsman.draw();
        prev_batsman_x   = snap_x;
        prev_batsman_img = snap_img;
      }

      // Ball drawn last so it appears on top
      cricket_ball.draw();

      // Delayed OUT screen: count down while the game keeps rendering
      // (broken stump visible, batsman swing finishing, etc.)
      // Show popup once timer expires AND batsman is back to idle.
      if(out_delay > 0){
        out_delay--;
        if(out_delay == 0 && !batsman.isSwinging()){
          game_paused = true;

          OutChoice_t choice = OutScreen();

          if(choice == OUT_CONTINUE){
            stump.reset();
            stump_timer = 0;
            score = 0;
            cricket_ball.speed = BALL_MIN_VY;
            cricket_ball.state = BALL_IDLE;
            cricket_ball.reset_timer = 0;
            bowler.reset();
            ST7735_FillScreen(BG_COLOR);
            ST7735_DrawBitmap(PITCH_X, PITCH_Y + PITCH_H - 1, pitch, PITCH_W, PITCH_H);
            bowler.dirty = true;   bowler.draw();
            stump.dirty = true;    stump.draw();
            batsman.dirty = true;  batsman.draw();
            prev_batsman_x = batsman.x;
            prev_batsman_img = batsman.image;
            wide_shown = false;
            game_paused = false;
          } else {
            back_to_home = true;
          }
          if(back_to_home) break;
          continue;
        } else if(out_delay == 0){
          out_delay = 1;
        }
      }

    } // end game loop
  } // end outer loop
}

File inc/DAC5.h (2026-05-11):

/**
 * @file      DAC5.h
 * @brief     5-bit binary-weighted DAC
 * @details   Lab 5. Digital Piano using a Digital to Analog Converter<br>
 * For more information see<br> https://docs.google.com/document/d/1DVmHjqsx24FvLp4x8KKyr5UmDeDlBlfeQPsVvKFQF_k/edit<br>
 * @version   ECE319K Fall 2025
 * @author    Your names go here
 * @copyright Lab solution, do not post,
 * @warning   AS-IS
 * @note      For more information see  http://users.ece.utexas.edu/~valvano/
 * @date      July 19, 2025
  <table>
<caption id="Lab5pins">Pins on the 5-bit DAC</caption>
<tr><th>Pin <th>GPIO<th>Hardware
<tr><td>PB4 <td>output<td>bit 4 (most significant)
<tr><td>PB3 <td>output<td>bit 3
<tr><td>PB2 <td>output<td>bit 2
<tr><td>PB1 <td>output<td>bit 1
<tr><td>PB0 <td>output<td>bit 0 (least significant)
</table>
  ******************************************************************************/
#ifndef __DAC5_H__
#define __DAC5_H__

/**
 * Initialize 5-bit DAC
 *    - PB4 output MSBit
 *    - PB3 output
 *    - PB2 output
 *    - PB1 output
 *    - PB0 output LSBit
 * @param none
 * @return none
 * @brief  Initialize DAC
 * @note LaunchPad_Init has been called; this program should not reset Port B
 */
void DAC5_Init(void);

/**
 * Output to 5-bit DAC
 * @param data is 5-bit value to output, 0 to 31
 * @return none
 * @brief  Output to DAC5
 * @note this solution must be friendly
 */
void DAC5_Out(uint32_t data);

#endif // __DAC5_H__

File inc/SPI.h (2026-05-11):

/*!
 * @defgroup SPI
 * @brief Synchronous serial communication
 <table>
<caption id="SPIpins">SPI-LCD pins </caption>
<tr><th>Pin <th>Function  <th>Description
<tr><td>PB9 <td>SPI1 SCLK <td>J1.7 LCD SPI clock (SPI)   
<tr><td>PB6 <td>SPI1 CS0  <td>J2.13 LCD SPI CS (SPI)     
<tr><td>PB8 <td>SPI1 PICO <td>J2.15 LCD SPI data (SPI)    
<tr><td>PB15<td>GPIO      <td>J2.17 LCD !RST =1 for run, =0 for reset   
<tr><td>PA13<td>GPIO      <td>J4.31 LCD RS =1 for data, =0 for command   
</table>
 * @{*/
/**
 * @file      SPI.h
 * @brief     Synchronous serial communication
 * @details   SPI uses a chip select, clock, data out and data in. This interface does not use data in.
 * This interface can be used for MKII LCD and the ST7735R LCD
 * \image html SPIinterface.png  width=500px
 * @version   ECE319K v1.2
 * @author    Daniel Valvano and Jonathan Valvano
 * @copyright Copyright 2025 by Jonathan W. Valvano, valvano@mail.utexas.edu,
 * @warning   AS-IS
 * @note      For more information see  http://users.ece.utexas.edu/~valvano/
 * @date      July 19, 2025
 <table>
<caption id="SPIpins2">SPI-LCD pins </caption>
<tr><th>Pin <th>Function  <th>Description
<tr><td>PB9 <td>SPI1 SCLK <td>J1.7 LCD SPI clock (SPI)   
<tr><td>PB6 <td>SPI1 CS0  <td>J2.13 LCD SPI CS (SPI)     
<tr><td>PB8 <td>SPI1 PICO <td>J2.15 LCD SPI data (SPI)    
<tr><td>PB15<td>GPIO      <td>J2.17 LCD !RST =1 for run, =0 for reset  
<tr><td>PA13<td>GPIO      <td>J4.31 LCD RS =1 for data, =0 for command   
</table>
  ******************************************************************************/
#ifndef __SPI_H__
#define __SPI_H__


/**
 * Initialize SPI for 8 MHz baud clock
 * using busy-wait synchronization.
 * Calls Clock_Freq to get bus clock
 * - PB9 SPI1 SCLK   
 * - PB6 SPI1 CS0       
 * - PB8 SPI1 PICO  
 * - PB15 GPIO !RST =1 for run, =0 for reset    
 * - PA13 GPIO RS =1 for data, =0 for command
 *
 * @note SPI0,SPI1 in power domain PD1 SysClk equals bus CPU clock
 * @param none
 * @return none 
 * @brief initialize SPI
 */
void SPI_Init(void);

/**
 * Output 8-bit data to SPI port.
 * RS=PA13=1 for data.
 * @param data is an 8-bit data to be transferred
 * @return none 
 * @brief Output data
 */
void SPI_OutData(char data);

/**
 * Output 8-bit command to SPI port.
 * RS=PA13=0 for command
 * @param  command is an 8-bit command to be transferred
 * @return none 
 * @brief Output command
 */
void SPI_OutCommand(char command);

/**
 *  Reset LCD 
 * -# drive RST high for 500ms
 * -# drive RST low for 500ms
 * -# drive RST high for 500ms
 * 
 * @param none
 * @return none 
 * @brief Reset LCD
 */
void SPI_Reset(void);
#endif // __SPI_H__
/** @}*/

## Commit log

2026-05-11 Final Changes
    [ColorConvert5-6-5.xlsx, CrickHit_PCB.kicad_pcb, CrickHit_PCB.kicad_sch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]
2026-05-11 Added stl of enclosure
    [Enclosure.stl, _Base Controller.c7203fb2-cdac-437a-b48d-505b96d81447.f3d, _Button Long.d1430e1f-5d8a-446c-85c3-4e6cc32e4bb1.f3d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]
